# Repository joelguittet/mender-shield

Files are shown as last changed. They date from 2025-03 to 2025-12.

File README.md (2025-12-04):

# mender-shield















The Mender Shield illustrates the capability to run a Mender client on heterogeneous platforms such as RaspberryPi (Linux based) and MCUs (RTOS/bare metal).

The following picture shows the Mender devices in the field with the mender-shield on the front, RaspberryPi and ESP32 platforms in the back:
- The Mender logo is displayed on the front of the shield, with an animation of the purple LEDs when an artifact is being downloaded.
- The background color indicates the connectivity status (blue is connected, green is idle, red in case of error).

mender-shield

The following picture shows both sides of the mender-shield:
- The RaspberryPi side has KTD2061 and KTD2058 LEDs drivers from [Kinetic technologies](https://www.kinet-ic.com/ktd2061) driving the 18 RGB LEDs (9 for each side of the PCB) and the [HAT ID EEPROM](https://datasheets.raspberrypi.com/hat/hat-plus-specification.pdf).
- The Arduino side has [ATECC608B](https://www.microchip.com/en-us/product/atecc608b) secure element used to authenticate the device and user EEPROM intented to store [Zephyr LLEXT](https://docs.zephyrproject.org/latest/services/llext/index.html) binary so that the shield also embeds the firmware used to control the display!

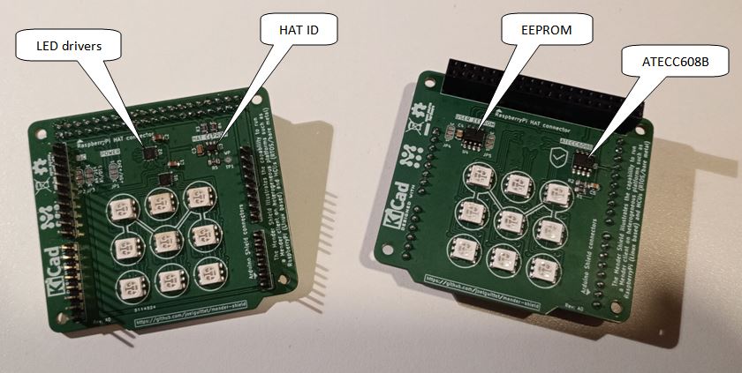
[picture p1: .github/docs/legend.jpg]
mender-shield


[Mender MCU client](https://github.com/joelguittet/mender-mcu-client) is an open source over-the-air (OTA) library updater for MCU devices. Check-out the source and demonstration examples!

## Hardware

The project has been created with [Kicad](https://www.kicad.org/), you can browse the project on [KiCanvas](https://kicanvas.org/?github=https%3A%2F%2Fgithub.com%2Fjoelguittet%2Fmender-shield%2Ftree%2Fmaster%2Fhardware). Gerber files used to manufacture the board are provided.

## Software

The software supports includes a script to perform a very simple demonstration on Raspberry Pi 3 device and an ESP-IDF based application used with the [Wemos D1 r32](.github/docs/Wemos-D1-R32.pdf) ESP32-based evaluation board.

## License

Copyright joelguittet and mender-mcu-client contributors

Licensed under the Apache License, Version 2.0 (the "License");
you may not use this file except in compliance with the License.
You may obtain a copy of the License at

    http://www.apache.org/licenses/LICENSE-2.0

Unless required by applicable law or agreed to in writing, software
distributed under the License is distributed on an "AS IS" BASIS,
WITHOUT WARRANTIES OR CONDITIONS OF ANY KIND, either express or implied.
See the License for the specific language governing permissions and
limitations under the License.

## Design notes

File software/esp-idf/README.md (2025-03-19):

# mender-shield | esp-idf





[Mender MCU client](https://github.com/joelguittet/mender-mcu-client) is an open source over-the-air (OTA) library updater for MCU devices. This demonstration project is used to demonstrate usage of mender-shield on ESP32 hardware.

## Getting started

This project is used with the [Wemos D1 r32](../../.github/docs/Wemos-D1-R32.pdf) ESP32-based evaluation board with 4MB flash. The installation of the mender-shield is done using the Arduino connector of the evaluation board.

The project is built using ESP-IDF framework. There is no other dependencies. Important note: the project has been tested with ESP-IDF v5.4.x successfully.

This project is developed under [VSCode](https://code.visualstudio.com) and using [ESP-IDF Extension](https://github.com/espressif/vscode-esp-idf-extension). If you need support to use the development environment, you can refer to the "ESP-IDF Extension help" section below.

Building and flashing the firmware on the device is done like for [mender-esp32-example](https://github.com/joelguittet/mender-esp32-example) that demonstrates the usage of mender-mcu-client on ESP32 MCU to perform upgrade with dual OTA partitions and rollback capability using ESP-IDF framework. Please refer to this example for more information about mender support in ESP-IDF environment.

To start using Mender, we recommend that you begin with the Getting started section in [the Mender documentation](https://docs.mender.io/).

### Open the project

Clone the project and retrieve submodules using `git submodule update --init --recursive`.

Then open the project with VSCode.

### Configuration of the application

The example application should first be configured to set at least:
- `CONFIG_MENDER_SERVER_TENANT_TOKEN` to set the Tenant Token of your account on "https://hosted.mender.io" server;
- `CONFIG_EXAMPLE_WIFI_SSID` and `CONFIG_EXAMPLE_WIFI_PASSWORD` to connect the device to your own WiFi access point.

You may want to customize few interesting settings:
- `CONFIG_MENDER_SERVER_HOST` if using your own Mender server instance. Tenant Token is not required in this case.
- `CONFIG_MENDER_CLIENT_AUTHENTICATION_POLL_INTERVAL` is the interval to retry authentication on the mender server.
- `CONFIG_MENDER_CLIENT_UPDATE_POLL_INTERVAL` is the interval to check for new deployments.
- `CONFIG_MENDER_CLIENT_INVENTORY_REFRESH_INTERVAL` is the interval to publish inventory data.
- `CONFIG_MENDER_CLIENT_CONFIGURE_REFRESH_INTERVAL` is the interval to refresh device configuration.

Other settings are available in the Kconfig. You can also refer to the mender-mcu-client API and configuration keys.

## Current status

The following states are handled by the application:
* Idle: the Mender logo is displayed on the front in night mode.
* Sync: the Mender logo is displayed on the front in day mode.
* Download: the Mender logo is blinking slowly.
* ArtifactInstall: the Mender logo is blinking fastly.

Additionally, the back side of the shield is blue when the Wi-Fi interface is connected, green if disconnected, red in case of errors.

## ESP-IDF Extension help

### Building

Using VSCode, first open the directory of the project.

Then go to Command Palette (Ctrl+Shift+P) and execute the `ESP-IDF: Set Espressif device target` command to select select an Espressif target. Choose `esp32`, then select `Custom board`.

Next execute the `ESP-IDF: SDK Configuration editor` command (Ctrl+E then G) to generate sdkconfig and optionally modify project settings. After all changes are made, click save and close this window.

Now build the project with the `ESP-IDF: Build your project` command (Ctrl+E then B). Progress is displayed in the terminal.

Binary is generated in the build directory.

You may optionally want to display the size of the executable with `ESP-IDF: Size analysis of the binaries` command (Ctrl+E then S).

### Flashing

First select the wanted serial port corresponding to the target with the `ESP-IDF: Select port to use` command (Ctrl+E then P).

Then invoke the `ESP-IDF: Flash your project` command (Ctrl+E then F) to flash the target. Choose `UART` option.

### Monitoring

Logs are displayed using the `ESP-IDF: Monitor your device` command (Ctrl+E then M).

## License

Copyright joelguittet and mender-mcu-client contributors

Licensed under the Apache License, Version 2.0 (the "License");
you may not use this file except in compliance with the License.
You may obtain a copy of the License at

    http://www.apache.org/licenses/LICENSE-2.0

Unless required by applicable law or agreed to in writing, software
distributed under the License is distributed on an "AS IS" BASIS,
WITHOUT WARRANTIES OR CONDITIONS OF ANY KIND, either express or implied.
See the License for the specific language governing permissions and
limitations under the License.

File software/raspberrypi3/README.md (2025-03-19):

# mender-shield | Raspberry Pi 3

The scripts provided in this directory are intended to demonstrate the usage of the mender-shield on Raspberry Pi 3 device.

## Getting started

The installation of the device should be done according to Mender documentation [Prepare a Raspberry Pi device](https://docs.mender.io/get-started/preparation/prepare-a-raspberry-pi-device) to properly setup and connect the Raspberry Pi to the Mender server.

The installation of the mender-shield is done using the 40 pins connector of the Raspberry Pi 3. Some spacers and screws are used to fix it on the device.

It is possible to verify the HAT is properly detected by running the following commands.

```
pi@raspberrypi:~ $ i2cdetect -y 0
     0  1  2  3  4  5  6  7  8  9  a  b  c  d  e  f
00:                         -- -- -- -- -- -- -- -- 
10: -- -- -- -- -- -- -- -- -- -- -- -- -- -- -- -- 
20: -- -- -- -- -- -- -- -- -- -- -- -- -- -- -- -- 
30: -- -- -- -- -- -- -- -- -- -- -- -- -- -- -- -- 
40: -- -- -- -- -- -- -- -- -- -- -- -- -- -- -- -- 
50: 50 -- -- -- -- -- -- -- -- -- -- -- -- -- -- -- 
60: -- -- -- -- -- -- -- -- -- -- -- -- -- -- -- -- 
70: -- -- -- -- -- -- -- --

pi@raspberrypi:~ $ i2cdetect -y 1
     0  1  2  3  4  5  6  7  8  9  a  b  c  d  e  f
00:                         -- -- -- -- -- -- -- -- 
10: -- -- -- -- -- -- -- -- -- -- -- -- -- -- -- -- 
20: -- -- -- -- -- -- -- -- -- -- -- -- -- -- -- -- 
30: -- -- -- -- -- -- -- -- -- -- -- -- -- -- -- -- 
40: -- -- -- -- -- -- -- -- -- -- -- -- -- -- -- -- 
50: 50 -- -- -- -- -- -- -- -- -- -- -- -- -- -- -- 
60: 60 -- -- -- -- -- -- -- 68 69 -- -- -- -- -- -- 
70: -- -- -- -- -- -- -- --
```

Where:
* 0x50 is the address of the HAT ID EEPROM connected on i2c-0.
* 0x50 is the address of the User EEPROM connected on i2c-1.
* 0x60 is the address of the ATECC608B connected on i2c-1.
* 0x68 and 0x69 are the addresses of the LED drivers connected on i2c-1.

Once the installation has been performed, you have to copy the `mender-shield-script` provided in this directory to the Raspberry Pi 3 device. Ensure it is executable.
Then create symlinks `/etc/mender/scripts/Idle_Enter_00` and `/etc/mender/scripts/Sync_Enter_10` to reference the `mender-shield-script` itself. Please be sure to respect the paths on the device, the default location for the State scripts is '/etc/mender/scripts'. See relevant documentation [State scripts](https://docs.mender.io/artifact-creation/state-scripts).

Reboot the device.

## Current status

Only the following states are managed by the script:
* Idle: the Mender logo is displayed on the front in night mode.
* Sync: the Mender logo is displayed on the front in day mode.

Additionally, the back side of the shield is blue if the mender server is reachable, red otherwise.

This could be enhanced to do nice demonstration and visual effects when an update is in progress.

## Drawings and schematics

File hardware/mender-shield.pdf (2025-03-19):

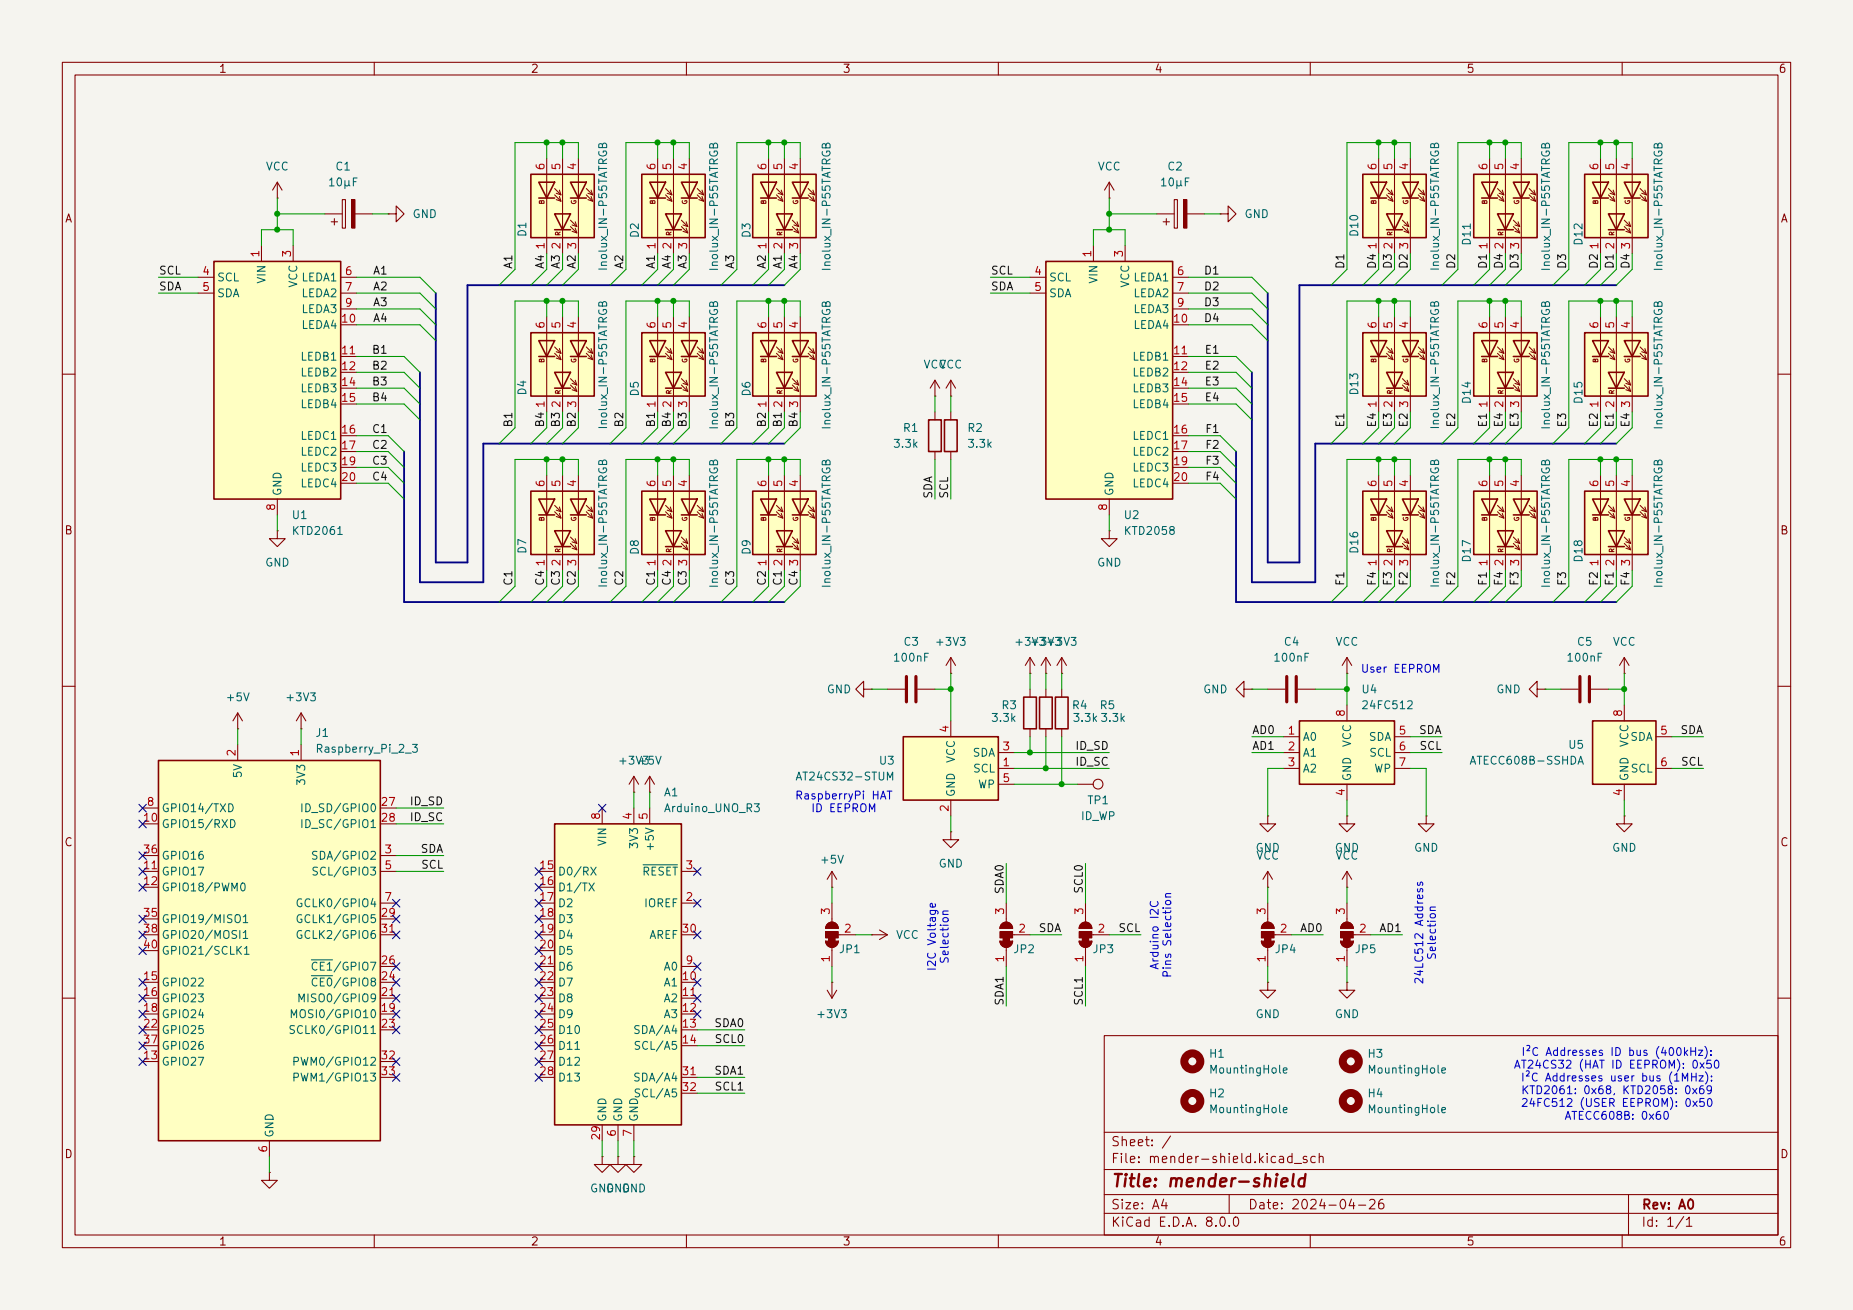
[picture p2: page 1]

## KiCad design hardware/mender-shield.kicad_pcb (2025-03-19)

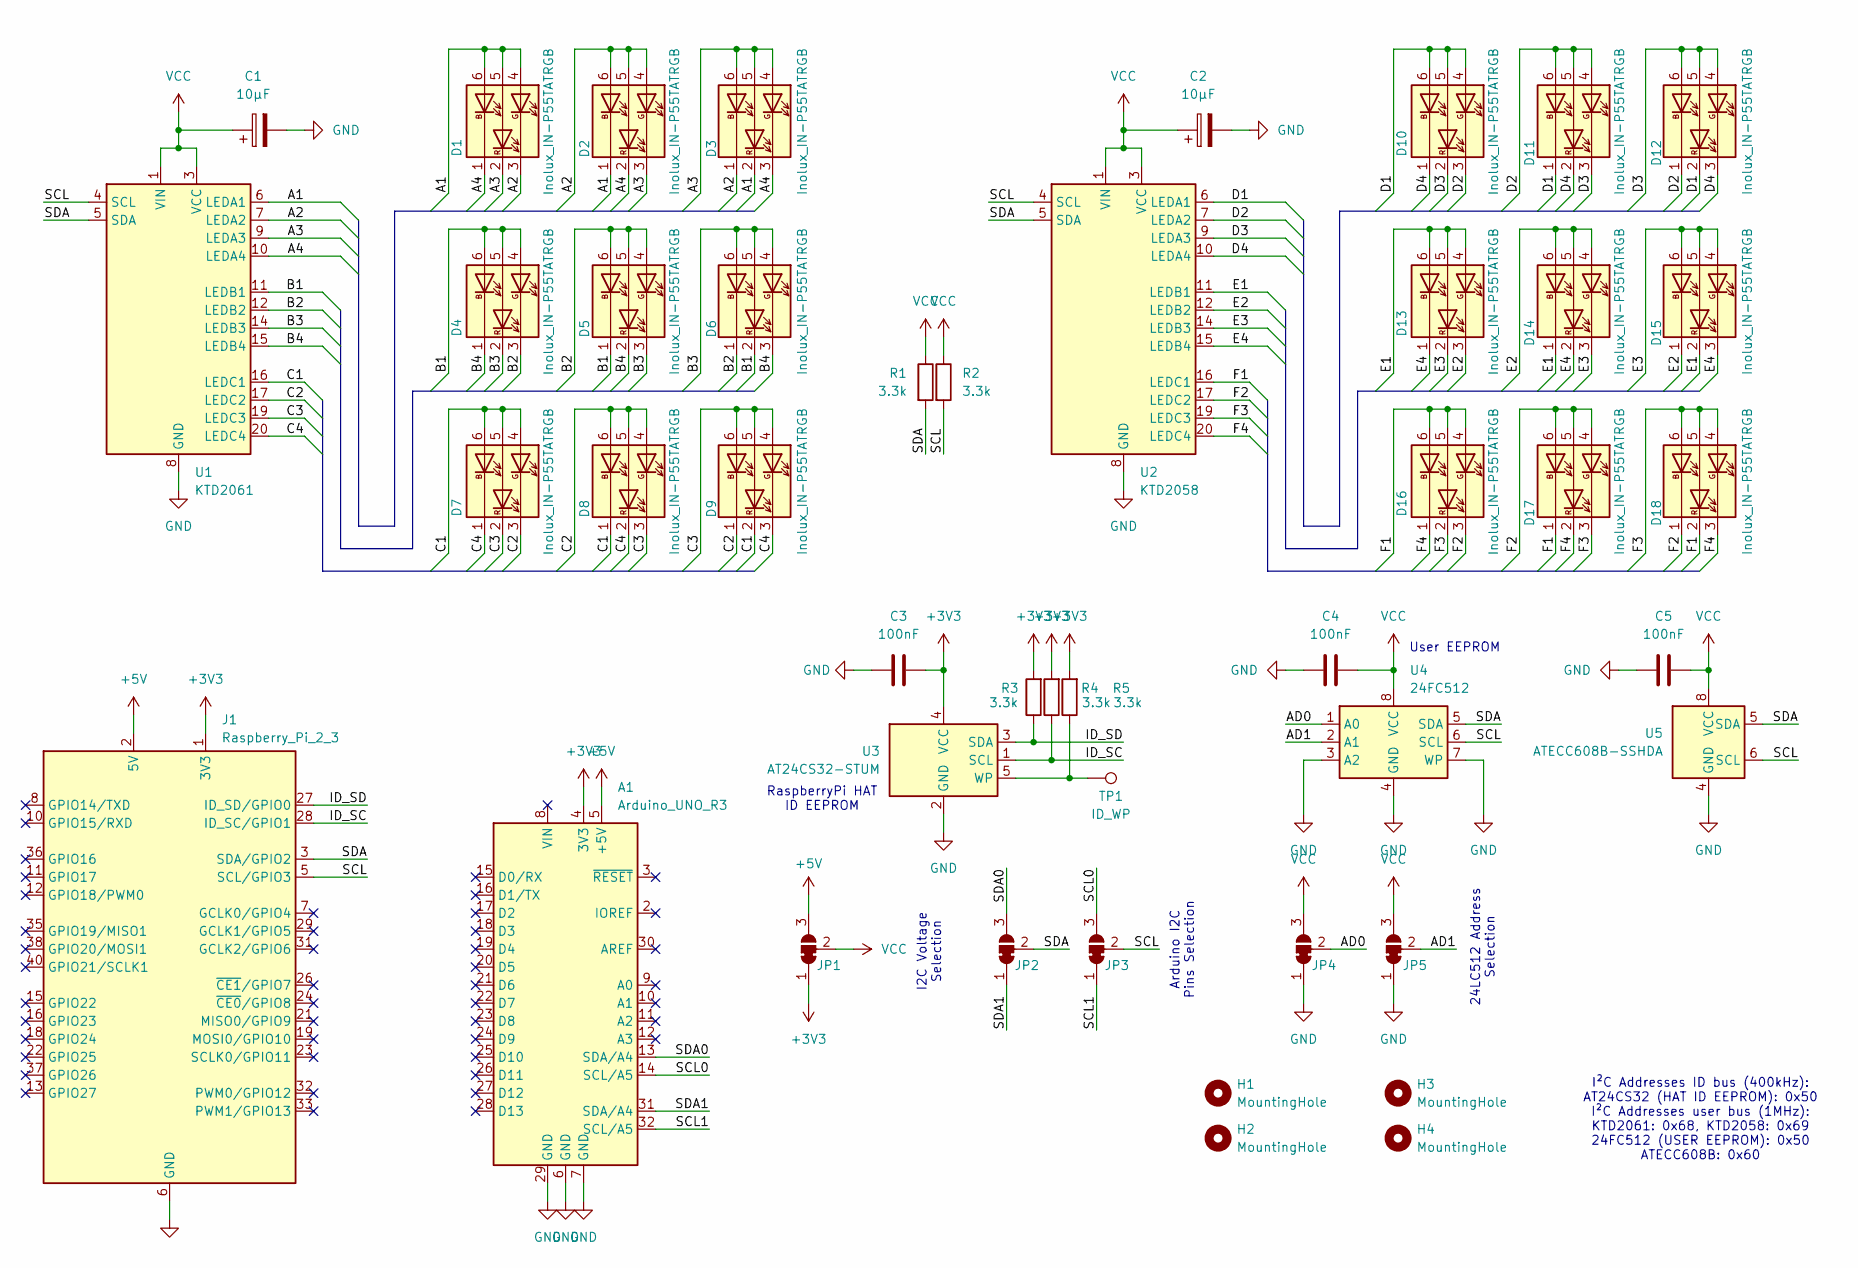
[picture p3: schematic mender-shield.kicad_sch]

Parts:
A1: Arduino_UNO_R3
C1, C2: 10µF; C_0805_2012Metric
C3, C4, C5: 100nF; C_0805_2012Metric
D1, D2, D3, D4, D5, D6, D7, D8, D9, D10, D11, D12, D13, D14, D15, D16, D17, D18: Inolux_IN-P55TATRGB; LED_Inolux_IN-P55TATRGB_PLCC6_5.0x5.5mm_P1.8mm
H1, H2, H3, H4: MountingHole; MountingHole_2.7mm_M2.5_DIN965
J1: Raspberry_Pi_2_3; PinSocket_2x20_P2.54mm_Vertical
JP1, JP2, JP3, JP4, JP5: SolderJumper_3_Bridged12; SolderJumper-3_P1.3mm_Bridged12_RoundedPad1.0x1.5mm_NumberL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
R1, R2, R3, R4, R5: 3.3k; R_0805_2012Metric
TP1: ID_WP; TestPoint_Pad_D1.5mm
U1: KTD2061; UQFN-20-1EP_3x3mm_P0.4mm_EP1.7x1.7mm_ThermalVias
U2: KTD2058; UQFN-20-1EP_3x3mm_P0.4mm_EP1.7x1.7mm_ThermalVias
U3: AT24CS32-STUM; SOT-23-5
U4: 24FC512; SOIC-8_3.9x4.9mm_P1.27mm
U5: ATECC608B-SSHDA; SOIC-8_3.9x4.9mm_P1.27mm

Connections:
+3V3: A1.4 (3V3), C3.2, J1.1 (3V3), J1.17 (3V3), JP1.1 (A), R3.2, R4.2, R5.2, U3.4 (VCC)
+5V: A1.5 (+5V), J1.2 (5V), J1.4 (5V), JP1.3 (B)
/A1: D1.4 (AG), D1.5 (AR), D1.6 (AB), D2.1 (KB), D3.2 (KR), U1.6 (LEDA1)
/A2: D1.3 (KG), D2.4 (AG), D2.5 (AR), D2.6 (AB), D3.1 (KB), U1.7 (LEDA2)
/A3: D1.2 (KR), D2.3 (KG), D3.4 (AG), D3.5 (AR), D3.6 (AB), U1.9 (LEDA3)
/A4: D1.1 (KB), D2.2 (KR), D3.3 (KG), U1.10 (LEDA4)
/AD0: JP4.2 (C), U4.1 (A0)
/AD1: JP5.2 (C), U4.2 (A1)
/B1: D4.4 (AG), D4.5 (AR), D4.6 (AB), D5.1 (KB), D6.2 (KR), U1.11 (LEDB1)
/B2: D4.3 (KG), D5.4 (AG), D5.5 (AR), D5.6 (AB), D6.1 (KB), U1.12 (LEDB2)
/B3: D4.2 (KR), D5.3 (KG), D6.4 (AG), D6.5 (AR), D6.6 (AB), U1.14 (LEDB3)
/B4: D4.1 (KB), D5.2 (KR), D6.3 (KG), U1.15 (LEDB4)
/C1: D7.4 (AG), D7.5 (AR), D7.6 (AB), D8.1 (KB), D9.2 (KR), U1.16 (LEDC1)
/C2: D7.3 (KG), D8.4 (AG), D8.5 (AR), D8.6 (AB), D9.1 (KB), U1.17 (LEDC2)
/C3: D7.2 (KR), D8.3 (KG), D9.4 (AG), D9.5 (AR), D9.6 (AB), U1.19 (LEDC3)
/C4: D7.1 (KB), D8.2 (KR), D9.3 (KG), U1.20 (LEDC4)
/D1: D10.4 (AG), D10.5 (AR), D10.6 (AB), D11.1 (KB), D12.2 (KR), U2.6 (LEDA1)
/D2: D10.3 (KG), D11.4 (AG), D11.5 (AR), D11.6 (AB), D12.1 (KB), U2.7 (LEDA2)
/D3: D10.2 (KR), D11.3 (KG), D12.4 (AG), D12.5 (AR), D12.6 (AB), U2.9 (LEDA3)
/D4: D10.1 (KB), D11.2 (KR), D12.3 (KG), U2.10 (LEDA4)
/E1: D13.4 (AG), D13.5 (AR), D13.6 (AB), D14.1 (KB), D15.2 (KR), U2.11 (LEDB1)
/E2: D13.3 (KG), D14.4 (AG), D14.5 (AR), D14.6 (AB), D15.1 (KB), U2.12 (LEDB2)
/E3: D13.2 (KR), D14.3 (KG), D15.4 (AG), D15.5 (AR), D15.6 (AB), U2.14 (LEDB3)
/E4: D13.1 (KB), D14.2 (KR), D15.3 (KG), U2.15 (LEDB4)
/F1: D16.4 (AG), D16.5 (AR), D16.6 (AB), D17.1 (KB), D18.2 (KR), U2.16 (LEDC1)
/F2: D16.3 (KG), D17.4 (AG), D17.5 (AR), D17.6 (AB), D18.1 (KB), U2.17 (LEDC2)
/F3: D16.2 (KR), D17.3 (KG), D18.4 (AG), D18.5 (AR), D18.6 (AB), U2.19 (LEDC3)
/F4: D16.1 (KB), D17.2 (KR), D18.3 (KG), U2.20 (LEDC4)
/ID_SC: J1.28 (ID_SC/GPIO1), R4.1, U3.1 (SCL)
/ID_SD: J1.27 (ID_SD/GPIO0), R3.1, U3.3 (SDA)
/SCL: J1.5 (SCL/GPIO3), JP3.2 (C), R2.2, U1.4 (SCL), U2.4 (SCL), U4.6 (SCL), U5.6 (SCL)
/SCL0: A1.14 (SCL/A5), JP3.3 (B)
/SCL1: A1.32 (SCL/A5), JP3.1 (A)
/SDA: J1.3 (SDA/GPIO2), JP2.2 (C), R1.2, U1.5 (SDA), U2.5 (SDA), U4.5 (SDA), U5.5 (SDA)
/SDA0: A1.13 (SDA/A4), JP2.3 (B)
/SDA1: A1.31 (SDA/A4), JP2.1 (A)
GND: A1.6 (GND), A1.7 (GND), A1.29 (GND), C1.2, C2.2, C3.1, C4.1, C5.1, J1.6 (GND), J1.9 (GND), J1.14 (GND), J1.20 (GND), J1.25 (GND), J1.30 (GND), J1.34 (GND), J1.39 (GND), JP4.1 (A), JP5.1 (A), U1.8 (GND), U1.13 (GND), U1.18 (GND), U1.21 (GND), U2.8 (GND), U2.13 (GND), U2.18 (GND), U2.21 (GND), U3.2 (GND), U4.3 (A2), U4.4 (GND), U4.7 (WP), U5.4 (GND)
unnamed: R5.1, TP1.1, U3.5 (WP)
VCC: C1.1, C2.1, C4.2, C5.2, JP1.2 (C), JP4.3 (B), JP5.3 (B), R1.1, R2.1, U1.1 (VIN), U1.2 (VIN), U1.3 (VCC), U2.1 (VIN), U2.2 (VIN), U2.3 (VCC), U4.8 (VCC), U5.8 (VCC)

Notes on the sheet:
RaspberryPi HAT ID EEPROM
Arduino I2C Pins Selection
I²C Addresses ID bus (400kHz): AT24CS32 (HAT ID EEPROM): 0x50 I²C Addresses user bus (1MHz): KTD2061: 0x68, KTD2058: 0x69 24FC512 (USER EEPROM): 0x50 ATECC608B: 0x60
User EEPROM
24LC512 Address Selection
I2C Voltage Selection

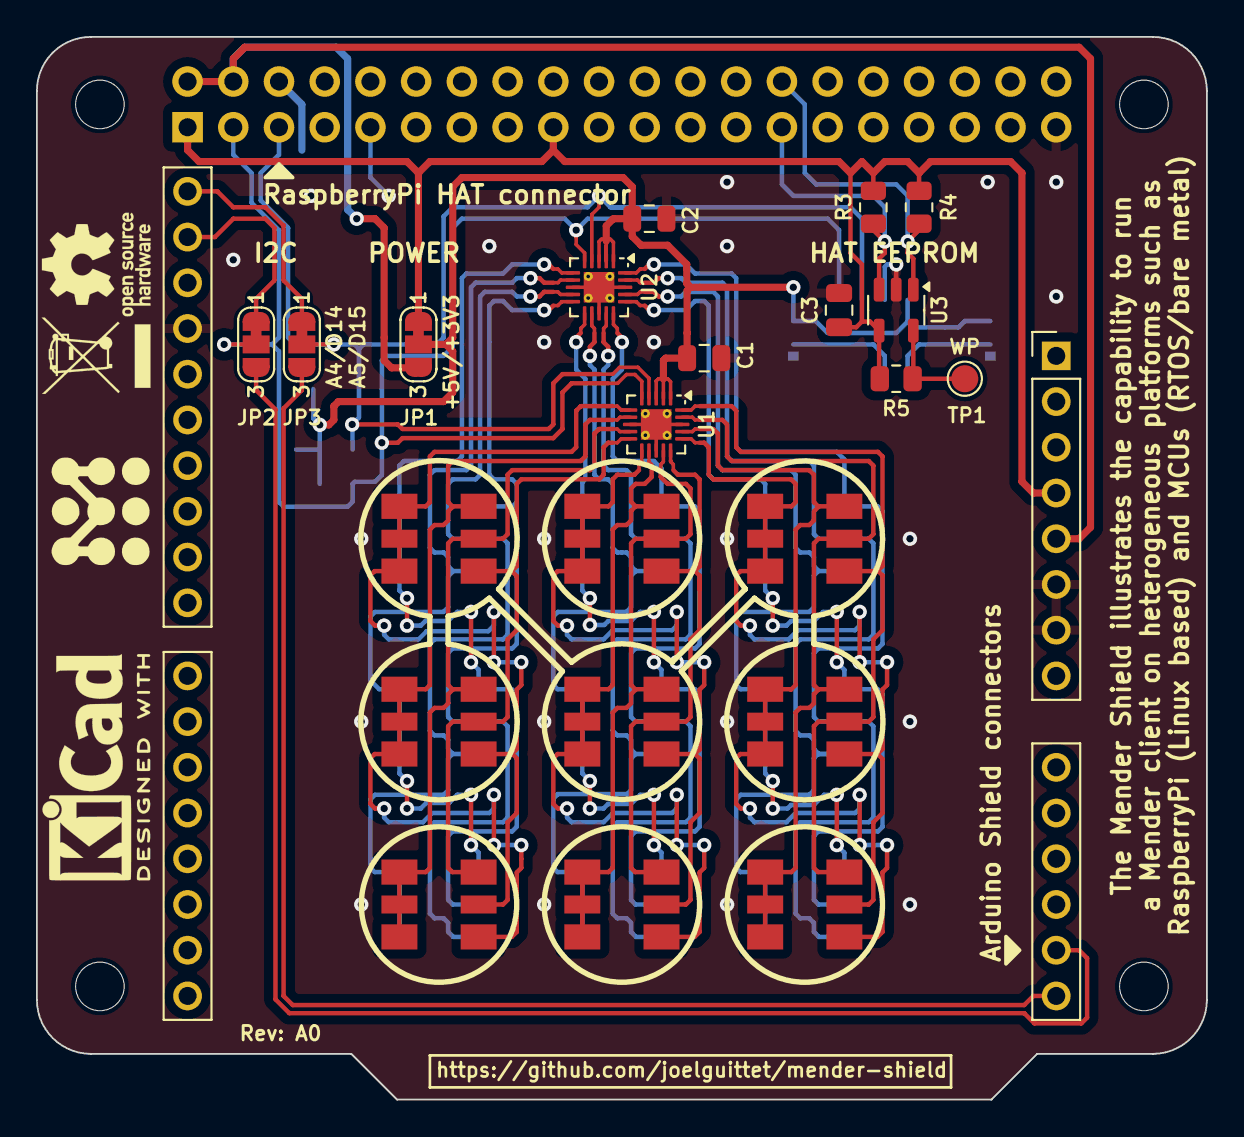
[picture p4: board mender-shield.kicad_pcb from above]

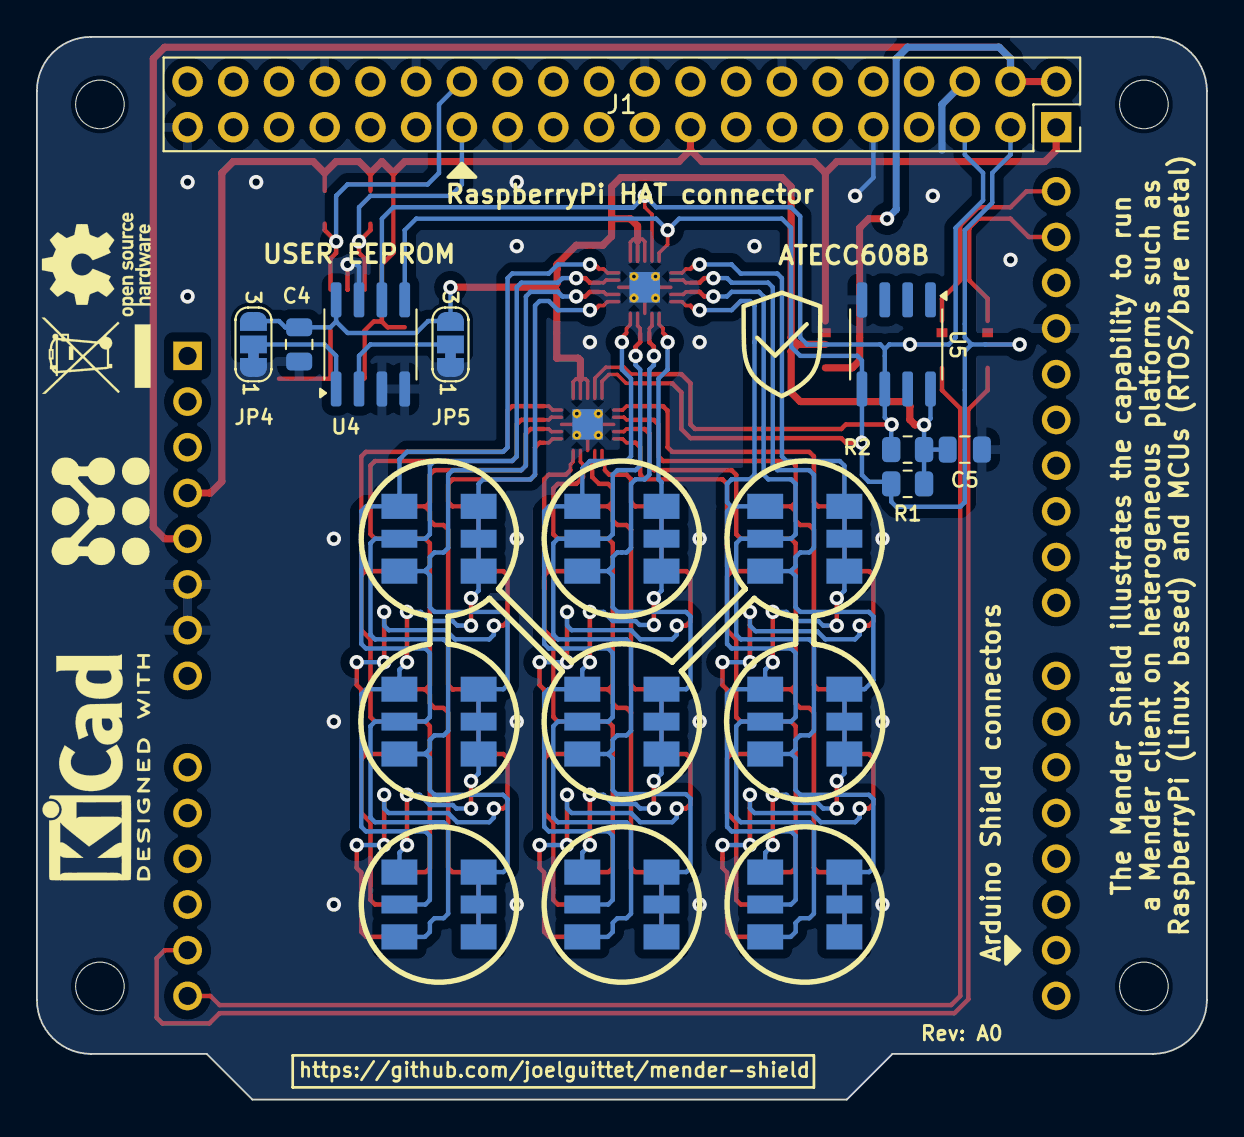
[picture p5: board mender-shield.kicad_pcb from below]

Board: 2 copper layers, 65.0 x 59.0 mm, 46 parts (19 on the bottom side), 39 nets.

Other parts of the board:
ATECC608B: LOGO; Trust-Logo_6x6mm_SilkScreen

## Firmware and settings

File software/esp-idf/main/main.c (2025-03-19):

/**
 * @file      main.c
 * @brief     Main entry point
 *
 * Copyright joelguittet and mender-mcu-client contributors
 *
 * Licensed under the Apache License, Version 2.0 (the "License");
 * you may not use this file except in compliance with the License.
 * You may obtain a copy of the License at
 *
 *     http://www.apache.org/licenses/LICENSE-2.0
 *
 * Unless required by applicable law or agreed to in writing, software
 * distributed under the License is distributed on an "AS IS" BASIS,
 * WITHOUT WARRANTIES OR CONDITIONS OF ANY KIND, either express or implied.
 * See the License for the specific language governing permissions and
 * limitations under the License.
 */

#include <stdio.h>
#include <driver/i2c.h>
#include <esp_event.h>
#ifdef CONFIG_MENDER_CLIENT_ADD_ON_TROUBLESHOOT
#ifdef CONFIG_MENDER_CLIENT_TROUBLESHOOT_FILE_TRANSFER
#include <esp_littlefs.h>
#endif /* CONFIG_MENDER_CLIENT_TROUBLESHOOT_FILE_TRANSFER */
#endif /* CONFIG_MENDER_CLIENT_ADD_ON_TROUBLESHOOT */
#include <esp_log.h>
#include <esp_mac.h>
#include <esp_ota_ops.h>
#include <freertos/FreeRTOS.h>
#include <freertos/event_groups.h>
#include <freertos/task.h>
#include "mender-client.h"
#include "mender-configure.h"
#include "mender-flash.h"
#include "mender-inventory.h"
#include "mender-troubleshoot.h"
#include <nvs_flash.h>
#include <protocol_examples_common.h>
#include <regex.h>
#include <sys/stat.h>
#include "sdkconfig.h"
#include <time.h>

/**
 * @brief Tag used for logging
 */
static const char *TAG = "main";

/**
 * @brief Mender client events
 */
static EventGroupHandle_t mender_client_events;
#define MENDER_CLIENT_EVENT_CONNECT      (1 << 0)
#define MENDER_CLIENT_EVENT_CONNECTED    (1 << 1)
#define MENDER_CLIENT_EVENT_DISCONNECT   (1 << 2)
#define MENDER_CLIENT_EVENT_DISCONNECTED (1 << 3)
#define MENDER_CLIENT_EVENT_RESTART      (1 << 4)

/**
 * @brief Mender shield events
 */
static EventGroupHandle_t mender_shield_events;
#define MENDER_SHIELD_EVENT_CONNECTING    (1 << 0)
#define MENDER_SHIELD_EVENT_CONNECTED     (1 << 1)
#define MENDER_SHIELD_EVENT_DISCONNECTING (1 << 2)
#define MENDER_SHIELD_EVENT_DISCONNECTED  (1 << 3)
#define MENDER_SHIELD_EVENT_AUTHENTICATED (1 << 4)
#define MENDER_SHIELD_EVENT_DOWNLOADING   (1 << 5)
#define MENDER_SHIELD_EVENT_INSTALLING    (1 << 6)
#define MENDER_SHIELD_EVENT_REBOOTING     (1 << 7)
#define MENDER_SHIELD_EVENT_SUCCESS       (1 << 8)
#define MENDER_SHIELD_EVENT_FAILURE       (1 << 9)

/**
 * @brief Mender shield I2C settings
 */
#define MENDER_SHIELD_I2C_MASTER_NUM            0
#define MENDER_SHIELD_I2C_MASTER_SCL_IO         22
#define MENDER_SHIELD_I2C_MASTER_SDA_IO         21
#define MENDER_SHIELD_I2C_MASTER_SDA_PULLUP     GPIO_PULLUP_ENABLE
#define MENDER_SHIELD_I2C_MASTER_SCL_PULLUP     GPIO_PULLUP_ENABLE
#define MENDER_SHIELD_I2C_MASTER_FREQ_HZ        100000
#define MENDER_SHIELD_I2C_MASTER_TX_BUF_DISABLE 0
#define MENDER_SHIELD_I2C_MASTER_RX_BUF_DISABLE 0
#define MENDER_SHIELD_I2C_MASTER_TIMEOUT_MS     1000

/**
 * @brief Mender shield I2C addresses
 */
#define MENDER_SHIELD_I2C_LED_DRIVER_BACK_ADDR  0x68
#define MENDER_SHIELD_I2C_LED_DRIVER_FRONT_ADDR 0x69

/**
 * @brief Mender shield I2C registers
 */
#define MENDER_SHIELD_I2C_LED_DRIVER_CONTROL_REGISTER 0x02

/**
 * @brief Mender shield background colors
 */
static const uint8_t MENDER_SHIELD_I2C_LED_DRIVER_BACKGROUND_RED[]
    = { MENDER_SHIELD_I2C_LED_DRIVER_CONTROL_REGISTER, 0x80, 0xFF, 0x00, 0x00, 0x00, 0x00, 0x00, 0x88, 0x80, 0x88, 0x80, 0x88, 0x80 };
static const uint8_t MENDER_SHIELD_I2C_LED_DRIVER_BACKGROUND_GREEN[]
    = { MENDER_SHIELD_I2C_LED_DRIVER_CONTROL_REGISTER, 0x80, 0x00, 0xFF, 0x00, 0x00, 0x00, 0x00, 0x88, 0x80, 0x88, 0x80, 0x88, 0x80 };
static const uint8_t MENDER_SHIELD_I2C_LED_DRIVER_BACKGROUND_BLUE[]
    = { MENDER_SHIELD_I2C_LED_DRIVER_CONTROL_REGISTER, 0x80, 0x00, 0x00, 0xFF, 0x00, 0x00, 0x00, 0x88, 0x80, 0x88, 0x80, 0x88, 0x80 };

/**
 * @brief Mender shield logo colors
 */
static const uint8_t MENDER_SHIELD_I2C_LED_DRIVER_FRONT_LOGO_NIGHT_MODE[]
    = { MENDER_SHIELD_I2C_LED_DRIVER_CONTROL_REGISTER, 0x42, 0x5D, 0x0F, 0x43, 0x01, 0x59, 0x69, 0x88, 0xF0, 0xF8, 0xF0, 0x88, 0xF0 };
static const uint8_t MENDER_SHIELD_I2C_LED_DRIVER_FRONT_LOGO_NORMAL_MODE[]
    = { MENDER_SHIELD_I2C_LED_DRIVER_CONTROL_REGISTER, 0x82, 0x5D, 0x0F, 0x43, 0x01, 0x59, 0x69, 0x88, 0xF0, 0xF8, 0xF0, 0x88, 0xF0 };

/**
 * @brief Network connnect callback
 * @return MENDER_OK if network is connected following the request, error code otherwise
 */
static mender_err_t
network_connect_cb(void) {

    ESP_LOGI(TAG, "Mender client connect network");

    /* This callback can be used to configure network connection */
    /* Note that the application can connect the network before if required */
    /* This callback only indicates the mender-client requests network access now */
    /* In this example, example_connect and example_disconnect configures Wi-Fi or Ethernet, as selected in menuconfig */
    /* Read "Establishing Wi-Fi or Ethernet Connection" section in examples/protocols/README.md for more information */
    xEventGroupSetBits(mender_client_events, MENDER_CLIENT_EVENT_CONNECT);
    EventBits_t bits = xEventGroupWaitBits(
        mender_client_events, MENDER_CLIENT_EVENT_CONNECTED | MENDER_CLIENT_EVENT_DISCONNECTED, pdTRUE, pdFALSE, 30000 / portTICK_PERIOD_MS);
    if (MENDER_CLIENT_EVENT_CONNECTED != (bits & MENDER_CLIENT_EVENT_CONNECTED)) {
        return MENDER_FAIL;
    }

    return MENDER_OK;
}

/**
 * @brief Network release callback
 * @return MENDER_OK if network is released following the request, error code otherwise
 */
static mender_err_t
network_release_cb(void) {

    ESP_LOGI(TAG, "Mender client released network");

    /* This callback can be used to release network connection */
    /* Note that the application can keep network activated if required */
    /* This callback only indicates the mender-client doesn't request network access now */
    xEventGroupSetBits(mender_client_events, MENDER_CLIENT_EVENT_DISCONNECT);

    return MENDER_OK;
}

/**
 * @brief Authentication success callback
 * @return MENDER_OK if application is marked valid and success deployment status should be reported to the server, error code otherwise
 */
static mender_err_t
authentication_success_cb(void) {

    mender_err_t ret;

    ESP_LOGI(TAG, "Mender client authenticated");
    xEventGroupSetBits(mender_shield_events, MENDER_SHIELD_EVENT_AUTHENTICATED);

#ifdef CONFIG_MENDER_CLIENT_ADD_ON_TROUBLESHOOT
    /* Activate troubleshoot add-on (deactivated by default) */
    if (MENDER_OK != (ret = mender_troubleshoot_activate())) {
        ESP_LOGE(TAG, "Unable to activate troubleshoot add-on");
        return ret;
    }
#endif /* CONFIG_MENDER_CLIENT_ADD_ON_TROUBLESHOOT */

    /* Validate the image if it is still pending */
    /* Note it is possible to do multiple diagnosic tests before validating the image */
    /* In this example, authentication success with the mender-server is enough */
    if (MENDER_OK != (ret = mender_flash_confirm_image())) {
        ESP_LOGE(TAG, "Unable to validate the image");
        return ret;
    }

    return ret;
}

/**
 * @brief Authentication failure callback
 * @return MENDER_OK if nothing to do, error code if the mender client should restart the application
 */
static mender_err_t
authentication_failure_cb(void) {

    static int tries = 0;

    /* Check if confirmation of the image is still pending */
    if (true == mender_flash_is_image_confirmed()) {
        ESP_LOGI(TAG, "Mender client authentication failed");
        return MENDER_OK;
    }

    /* Increment number of failures */
    tries++;
    ESP_LOGE(TAG, "Mender client authentication failed (%d/%d)", tries, CONFIG_EXAMPLE_AUTHENTICATION_FAILS_MAX_TRIES);
    xEventGroupSetBits(mender_shield_events, MENDER_SHIELD_EVENT_FAILURE);

    /* Restart the application after several authentication failures with the mender-server */
    /* The image has not been confirmed and the bootloader will now rollback to the previous working image */
    /* Note it is possible to customize this depending of the wanted behavior */
    return (tries >= CONFIG_EXAMPLE_AUTHENTICATION_FAILS_MAX_TRIES) ? MENDER_FAIL : MENDER_OK;
}

/**
 * @brief Deployment status callback
 * @param status Deployment status value
 * @param desc Deployment status description as string
 * @return MENDER_OK if the function succeeds, error code otherwise
 */
static mender_err_t
deployment_status_cb(mender_deployment_status_t status, char *desc) {

    /* We can do something else if required */
    ESP_LOGI(TAG, "Deployment status is '%s'", desc);

    /* Raise mender-shield event depending of the status */
    switch (status) {
        case MENDER_DEPLOYMENT_STATUS_DOWNLOADING:
            xEventGroupSetBits(mender_shield_events, MENDER_SHIELD_EVENT_DOWNLOADING);
            break;
        case MENDER_DEPLOYMENT_STATUS_INSTALLING:
            xEventGroupSetBits(mender_shield_events, MENDER_SHIELD_EVENT_INSTALLING);
            break;
        case MENDER_DEPLOYMENT_STATUS_REBOOTING:
            xEventGroupSetBits(mender_shield_events, MENDER_SHIELD_EVENT_REBOOTING);
            break;
        case MENDER_DEPLOYMENT_STATUS_SUCCESS:
            xEventGroupSetBits(mender_shield_events, MENDER_SHIELD_EVENT_SUCCESS);
            break;
        case MENDER_DEPLOYMENT_STATUS_FAILURE:
            xEventGroupSetBits(mender_shield_events, MENDER_SHIELD_EVENT_FAILURE);
            break;
        default:
            break;
    }

    return MENDER_OK;
}

/**
 * @brief Restart callback
 * @return MENDER_OK if the function succeeds, error code otherwise
 */
static mender_err_t
restart_cb(void) {

    /* Application is responsible to shutdown and restart the system now */
    xEventGroupSetBits(mender_client_events, MENDER_CLIENT_EVENT_RESTART);

    return MENDER_OK;
}

#ifdef CONFIG_MENDER_CLIENT_ADD_ON_CONFIGURE
#ifndef CONFIG_MENDER_CLIENT_CONFIGURE_STORAGE

/**
 * @brief Device configuration updated
 * @param configuration Device configuration
 * @return MENDER_OK if the function succeeds, error code otherwise
 */
static mender_err_t
config_updated_cb(mender_keystore_t *configuration) {

    /* Application can use the new device configuration now */
    /* In this example, we just print the content of the configuration received from the Mender server */
    if (NULL != configuration) {
        size_t index = 0;
        ESP_LOGI(TAG, "Device configuration received from the server");
        while ((NULL != configuration[index].name) && (NULL != configuration[index].value)) {
            ESP_LOGI(TAG, "Key=%s, value=%s", configuration[index].name, configuration[index].value);
            index++;
        }
    }

    return MENDER_OK;
}

#endif /* CONFIG_MENDER_CLIENT_CONFIGURE_STORAGE */
#endif /* CONFIG_MENDER_CLIENT_ADD_ON_CONFIGURE */

#ifdef CONFIG_MENDER_CLIENT_ADD_ON_TROUBLESHOOT
#ifdef CONFIG_MENDER_CLIENT_TROUBLESHOOT_FILE_TRANSFER

static mender_err_t
file_transfer_stat_cb(char *path, size_t **size, uint32_t **uid, uint32_t **gid, uint32_t **mode, time_t **time) {

    assert(NULL != path);
    struct stat  stats;
    mender_err_t ret = MENDER_OK;

    /* Get statistics of file */
    if (0 != stat(path, &stats)) {
        ESP_LOGE(TAG, "Unable to get statistics of file '%s'", path);
        ret = MENDER_FAIL;
        goto FAIL;
    }
    /* Size is optional */
    if (NULL != size) {
        if (NULL == (*size = (size_t *)malloc(sizeof(size_t)))) {
            ESP_LOGE(TAG, "Unable to allocate memory");
            ret = MENDER_FAIL;
            goto FAIL;
        }
        **size = stats.st_size;
    }
    /* UID and GID are optional */
    if (NULL != uid) {
        if (NULL == (*uid = (uint32_t *)malloc(sizeof(uint32_t)))) {
            ESP_LOGE(TAG, "Unable to allocate memory");
            ret = MENDER_FAIL;
            goto FAIL;
        }
        **uid = stats.st_uid;
    }
    if (NULL != gid) {
        if (NULL == (*gid = (uint32_t *)malloc(sizeof(uint32_t)))) {
            ESP_LOGE(TAG, "Unable to allocate memory");
            ret = MENDER_FAIL;
            goto FAIL;
        }
        **gid = stats.st_gid;
    }
    /* Mode is not optional and file must be a regular file to be downloaded by the server */
    if (NULL != mode) {
        if (NULL == (*mode = (uint32_t *)malloc(sizeof(uint32_t)))) {
            ESP_LOGE(TAG, "Unable to allocate memory");
            ret = MENDER_FAIL;
            goto FAIL;
        }
        **mode = stats.st_mode;
    }
    /* Last modification time is optional, format seconds since epoch */
    if (NULL != time) {
        if (NULL == (*time = (time_t *)malloc(sizeof(time_t)))) {
            ESP_LOGE(TAG, "Unable to allocate memory");
            ret = MENDER_FAIL;
            goto FAIL;
        }
        **time = stats.st_mtim.tv_sec;
    }

FAIL:

    return ret;
}

static mender_err_t
file_transfer_open_cb(char *path, char *mode, void **handle) {

    assert(NULL != path);
    assert(NULL != mode);

    /* Open file */
    ESP_LOGI(TAG, "Opening file '%s' with mode '%s'", path, mode);
    if (NULL == (*handle = (void *)fopen(path, mode))) {
        ESP_LOGE(TAG, "Unable to open file '%s'", path);
        return MENDER_FAIL;
    }

    return MENDER_OK;
}

static mender_err_t
file_transfer_read_cb(void *handle, void *data, size_t *length) {

    assert(NULL != handle);
    assert(NULL != data);
    assert(NULL != length);

    /* Read file */
    *length = fread(data, sizeof(uint8_t), *length, (FILE *)handle);

    return MENDER_OK;
}
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
void
app_main(void) {

    /* Initialize NVS */
    esp_err_t ret = nvs_flash_init();
    if ((ESP_ERR_NVS_NO_FREE_PAGES == ret) || (ESP_ERR_NVS_NEW_VERSION_FOUND == ret)) {
        ESP_LOGI(TAG, "Erasing flash...");
        ESP_ERROR_CHECK(nvs_flash_erase());
        ret = nvs_flash_init();
    }
    ESP_ERROR_CHECK(ret);

#ifdef CONFIG_MENDER_CLIENT_ADD_ON_TROUBLESHOOT
#ifdef CONFIG_MENDER_CLIENT_TROUBLESHOOT_FILE_TRANSFER

    /* Initialize LittleFS */
    esp_vfs_littlefs_conf_t littlefs_conf = {
        .base_path              = "/littlefs",
        .partition_label        = "storage",
        .format_if_mount_failed = true,
        .dont_mount             = false,
    };
    ret = esp_vfs_littlefs_register(&littlefs_conf);
    if (ESP_OK != ret) {
        if (ESP_FAIL == ret) {
            ESP_LOGE(TAG, "Failed to mount or format filesystem");
        } else if (ESP_ERR_NOT_FOUND == ret) {
            ESP_LOGE(TAG, "Failed to find LittleFS partition");
        } else {
            ESP_LOGE(TAG, "Failed to initialize LittleFS (%s)", esp_err_to_name(ret));
        }
    }
    ESP_ERROR_CHECK(ret);
    size_t total = 0, used = 0;
    ret = esp_littlefs_info(littlefs_conf.partition_label, &total, &used);
    if (ESP_OK != ret) {
        ESP_LOGE(TAG, "Failed to get LittleFS partition information (%s)", esp_err_to_name(ret));
        esp_littlefs_format(littlefs_conf.partition_label);
    } else {
        ESP_LOGI(TAG, "LittleFS partition size: total: %d, used: %d", total, used);
    }
    ESP_ERROR_CHECK(ret);

#endif /* CONFIG_MENDER_CLIENT_TROUBLESHOOT_FILE_TRANSFER */
#endif /* CONFIG_MENDER_CLIENT_ADD_ON_TROUBLESHOOT */

    /* Initialize network */
    ESP_ERROR_CHECK(esp_netif_init());
    ESP_ERROR_CHECK(esp_event_loop_create_default());

    /* Read base MAC address of the device */
    uint8_t mac[6];
    char    mac_address[18];
    ESP_ERROR_CHECK(esp_read_mac(mac, ESP_MAC_WIFI_STA));
    sprintf(mac_address, "%02x:%02x:%02x:%02x:%02x:%02x", mac[0], mac[1], mac[2], mac[3], mac[4], mac[5]);
    ESP_LOGI(TAG, "MAC address of the device '%s'", mac_address);

    /* Create mender-client event group */
    mender_client_events = xEventGroupCreate();
    ESP_ERROR_CHECK(NULL == mender_client_events);

    /* Create mender-shield event group */
    mender_shield_events = xEventGroupCreate();
    ESP_ERROR_CHECK(NULL == mender_shield_events);

    /* Initialize mender-shield hardware */
    ESP_ERROR_CHECK(shield_init());

    /* Create mender-shield task */
    ESP_ERROR_CHECK(pdPASS != xTaskCreate(shield_task, "shield_task", 4096, NULL, tskIDLE_PRIORITY, NULL));

    /* Retrieve running version of the device */
    esp_app_desc_t         running_app_info;
    const esp_partition_t *running = esp_ota_get_running_partition();
    ESP_ERROR_CHECK(esp_ota_get_partition_description(running, &running_app_info));
    ESP_LOGI(TAG, "Running project '%s' version '%s'", running_app_info.project_name, running_app_info.version);

    /* Compute artifact name */
    char artifact_name[128];
    sprintf(artifact_name, "%s-v%s", running_app_info.project_name, running_app_info.version);

    /* Retrieve device type */
    char *device_type = running_app_info.project_name;

    /* Initialize mender-client */
    mender_keystore_t         identity[]              = { { .name = "mac", .value = mac_address }, { .name = NULL, .value = NULL } };
    mender_client_config_t    mender_client_config    = { .identity                     = identity,
                                                          .artifact_name                = artifact_name,
                                                          .device_type                  = device_type,
                                                          .host                         = NULL,
                                                          .tenant_token                 = NULL,
                                                          .authentication_poll_interval = 0,
                                                          .update_poll_interval         = 0,
                                                          .recommissioning              = false };
    mender_client_callbacks_t mender_client_callbacks = { .network_connect        = network_connect_cb,
                                                          .network_release        = network_release_cb,
                                                          .authentication_success = authentication_success_cb,
                                                          .authentication_failure = authentication_failure_cb,
                                                          .deployment_status      = deployment_status_cb,
                                                          .restart                = restart_cb };
    ESP_ERROR_CHECK(mender_client_init(&mender_client_config, &mender_client_callbacks));
    ESP_LOGI(TAG, "Mender client initialized");

    /* Initialize mender add-ons */
#ifdef CONFIG_MENDER_CLIENT_ADD_ON_CONFIGURE
    mender_configure_config_t    mender_configure_config    = { .refresh_interval = 0 };
    mender_configure_callbacks_t mender_configure_callbacks = {
#ifndef CONFIG_MENDER_CLIENT_CONFIGURE_STORAGE
        .config_updated = config_updated_cb,
#endif /* CONFIG_MENDER_CLIENT_CONFIGURE_STORAGE */
    };
    ESP_ERROR_CHECK(mender_client_register_addon(
        (mender_addon_instance_t *)&mender_configure_addon_instance, (void *)&mender_configure_config, (void *)&mender_configure_callbacks));
    ESP_LOGI(TAG, "Mender configure add-on registered");
#endif /* CONFIG_MENDER_CLIENT_ADD_ON_CONFIGURE */
#ifdef CONFIG_MENDER_CLIENT_ADD_ON_INVENTORY
    mender_inventory_config_t mender_inventory_config = { .refresh_interval = 0 };
    ESP_ERROR_CHECK(mender_client_register_addon((mender_addon_instance_t *)&mender_inventory_addon_instance, (void *)&mender_inventory_config, NULL));
    ESP_LOGI(TAG, "Mender inventory add-on registered");
#endif /* CONFIG_MENDER_CLIENT_ADD_ON_INVENTORY */
#ifdef CONFIG_MENDER_CLIENT_ADD_ON_TROUBLESHOOT
    mender_troubleshoot_config_t    mender_troubleshoot_config    = { .host = NULL, .healthcheck_interval = 0 };
    mender_troubleshoot_callbacks_t mender_troubleshoot_callbacks = {
#ifdef CONFIG_MENDER_CLIENT_TROUBLESHOOT_FILE_TRANSFER
        .file_transfer = { .stat  = file_transfer_stat_cb,
                           .open  = file_transfer_open_cb,
                           .read  = file_transfer_read_cb,
                           .write = file_transfer_write_cb,
                           .close = file_transfer_close_cb },
#endif /* CONFIG_MENDER_CLIENT_TROUBLESHOOT_FILE_TRANSFER */
#ifdef CONFIG_MENDER_CLIENT_TROUBLESHOOT_PORT_FORWARDING
        .port_forwarding = { .connect = NULL, .send = NULL, .close = NULL },
#endif /* CONFIG_MENDER_CLIENT_TROUBLESHOOT_PORT_FORWARDING */
#ifdef CONFIG_MENDER_CLIENT_TROUBLESHOOT_SHELL
        .shell = { .open = shell_open_cb, .resize = shell_resize_cb, .write = shell_write_cb, .close = shell_close_cb }
#endif /* CONFIG_MENDER_CLIENT_TROUBLESHOOT_SHELL */
    };
    ESP_ERROR_CHECK(mender_client_register_addon(
        (mender_addon_instance_t *)&mender_troubleshoot_addon_instance, (void *)&mender_troubleshoot_config, (void *)&mender_troubleshoot_callbacks));
    ESP_LOGI(TAG, "Mender troubleshoot add-on registered");
#endif /* CONFIG_MENDER_CLIENT_ADD_ON_TROUBLESHOOT */

#ifdef CONFIG_MENDER_CLIENT_ADD_ON_CONFIGURE
    /* Get mender configuration (this is just an example to illustrate the API) */
    mender_keystore_t *configuration;
    if (MENDER_OK != mender_configure_get(&configuration)) {
        ESP_LOGE(TAG, "Unable to get mender configuration");
    } else if (NULL != configuration) {
        size_t index = 0;
        ESP_LOGI(TAG, "Device configuration retrieved");
        while ((NULL != configuration[index].name) && (NULL != configuration[index].value)) {
            ESP_LOGI(TAG, "Key=%s, value=%s", configuration[index].name, configuration[index].value);
            index++;
        }
        mender_utils_keystore_delete(configuration);
    }
#endif /* CONFIG_MENDER_CLIENT_ADD_ON_CONFIGURE */
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

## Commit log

2025-03-19 Initial release
    [mender-shield-B_Adhesive.gbr, mender-shield-B_Cu.gbr, mender-shield-B_Mask.gbr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]
2025-03-19 software: add raspberrypi3 demonstration script
2025-03-19 software: add esp-idf firmware
    [partitions.csv]
2025-12-04 workflows: update sonarcloud integration
